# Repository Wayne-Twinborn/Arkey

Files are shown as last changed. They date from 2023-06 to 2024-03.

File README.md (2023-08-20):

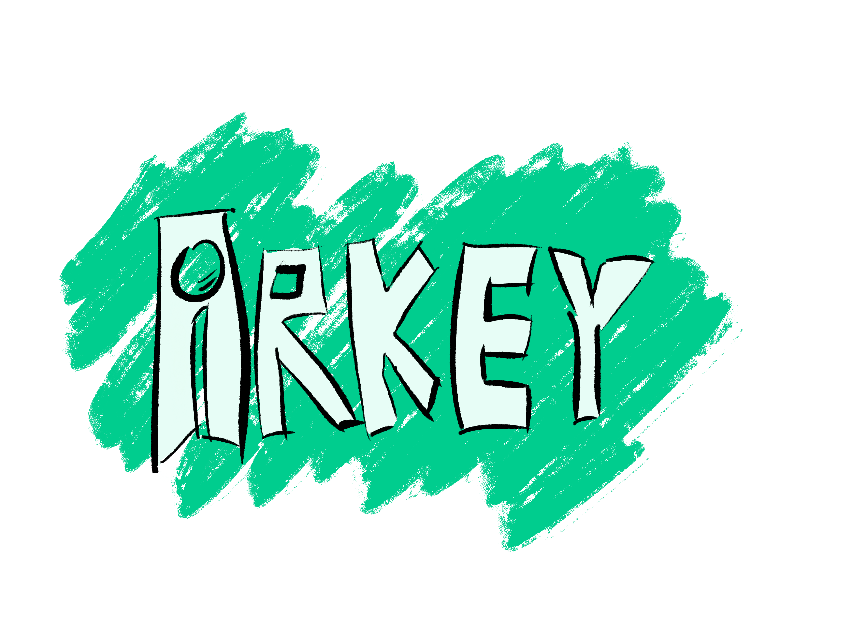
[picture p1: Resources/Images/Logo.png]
Arkey

Arcade Keyboard. Intended to be a super small form factor WASD controller for fighting games that's cheap and easy to source.  

## TLDR/I wanna get one  
If you want to build it yourself, check the "MakeMe" folder. You'll have to build it. I don't sell them at the moment. I'll probably gift off the batch of PCB I made. This project is to allow individuals and companies to have a cheap and easy option to build a stick. 

## About the project
This is a pet project because the only company (at the time I started) that was making super small form factor leverless controllers had all but abandoned their WASD line.   
Traditional leverless style (with up at the bottom of the controller) hurts my wrists and is unintuitive to me. This fixes both issues.   
My goal of giving myself a controller that suits my needs has been met. I'll continue to iterate on the design, but I want to turn it over to the community.   

# Versions
### ArkeyV1
This is the easiest one to build and source parts for. It uses standard 5 pin MX keyswitches and a pico with headers, hard soldered to the PCB. It's the largest entry in the project.

### ArkeyV2
This is a significantly improved Arkey. Much smaller size, uses hot swap sockets and switches, and the case can be printed on printers with a bed of around 190mmx 115mm. This is harder to assemble than the V1 by virtue of surface mounting the Pico and using hot swap sockets instead of mounting the switches directly. This is the recommended version of the Arkey.

### Arkey Nano V1
This is a version of the Arkey that uses keycaps instead of button caps. It's designed, effectively, to be an ergonomic keyboard to play on. This is the smallest option and it's easier to source keycaps than it is to source button caps.

### Licensing
This project is under the open source hardware license. Details are in the LICENSE file.
A short version is that you can distribute, produce, or modify as you like. No warranty or liabilty. 
I would be happy to see people building and selling the Arkey. 

## Contributing
If you want to contribute, the "Source" folder has all you need to work on the design. All of the tools I used to make it are freely available. And if you don't like them, there are plenty of alternatives. Chances are if you're going to dive into it  you already have tool preferences. 

#### Dev tools
- EasyEDA: PCB design for the V1 Arkey
- Kicad: PCB design for all other models. 
- FreeCAD: Case design  
- Krita: Art template  

### Contribution Requirements
You must include a description of what you've done and you must have a working prototype (meaning fully assembled PCB) on hand. 

I did this for free and will continue working on it when time and money allows, but if you do want to tip, here's my Ko-fi.
https://ko-fi.com/aloehart

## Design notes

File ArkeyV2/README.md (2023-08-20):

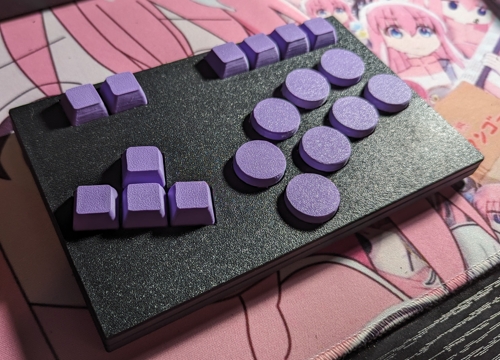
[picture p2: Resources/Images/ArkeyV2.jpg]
Arkey Nano

# Arkey V2  
This is the Arkey V2, a WASD based micro stick .  

## V2 Features  
- Hot swap socket design  
- Surface mount Pico (tested with waveshare usb-c pico as well)  
- Multiple 3D print case options  
- Significantly smaller form factor over V1    

Note: You can use whatever switches and cap designs you want that fit the sockets. This was designed for (and tested with) Choc v2.  
  
Pins (Using Xbox notation)  

Up:	11  
Down:	12  
Left:	10  
Right:	13  
A:	14  
B:	16  
X:	15  
Y:	17  
RT:	18  
RB:	19  
LT:	21  
LB:	20  
Start:	0  
Back:	1  
L3:	27   
R3: 	26  
Guide:	28  
Record: 22

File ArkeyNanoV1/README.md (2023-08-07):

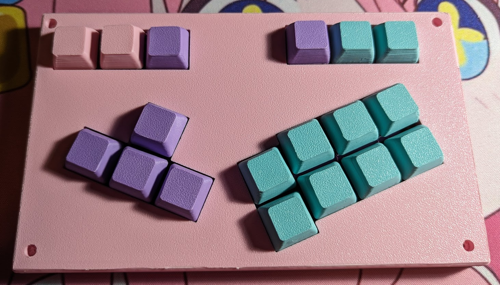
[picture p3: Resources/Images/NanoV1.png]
Arkey Nano


# Arkey Nano 
The Nano is a side project for Arkey. A form factor that's even smaller by basically making an ergonomic keyboard layout.

### Features:
- Incredibly small size
- Hot swap key switch mounts
- All the other features of the Arkey

### Requirements:
- PCB
- 18 Kailh hot swap sockets
- 18 Choc switches of your preference
- Key caps to fit the siwtches
- Raspberry Pi Pico (will be soldered surface mount)

### Reference the files in "MakeMe" for how to build it. 
### If you want to contribute, check the Readme in the source folder.

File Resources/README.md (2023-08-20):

This folder contains resources such as images and accessory STL files.

## MX Keycaps 
This is a flat topped MX key cap for 3d printing. An FDM printer should be able to print it with the top of the cap flat on the build plate without any supports. 

## Display Hooks
This is a simple hook design I threw together to hang my controllers with. Uploaded here by request.

## flash_nuke.uf2
A file that wipes your RP2040. When in doubt, use this to reset to a clean start.

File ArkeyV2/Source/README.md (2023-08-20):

# Tools used
- Kicad
- Freecad

# Firmware
Firmware is handled by the GP-2040-CE project. Arkey specifically just alters the Pico config to create its UF2.

# Rules
Anything you submit you must have a working prototype of first

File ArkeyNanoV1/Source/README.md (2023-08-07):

If you want to contribute, make sure you have a working prototype with your changes.

Documentation updates you can just push.

## Tools
- Kicad
- Freecad

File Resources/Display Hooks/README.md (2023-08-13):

These are simple hooks you can hang on your wall to display Arkey controllers. 

Screw.stl uses a screw and is countersunk into the hook. This has the highest weight limit (though I don't know how much and I wouldn't put any more than a controller on these).

Nail.stl is the same hook but designed to use a "picture hanging nail" to hang.a

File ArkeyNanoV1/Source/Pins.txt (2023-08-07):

1/start: pin 0 
2/select: pin 1
3/home/A1: pin 2
4/ls: 28
5/rs: 27
6/cap/A2: 26
D: 14
S: 13
A: 11
W: 12
K1/B1: 15
K2/B2: 18
K3/R2: 20
K4/L2: 22
P1/B3: 16
P2/B4: 17 (S2/config)
P3/R1: 19
P4/L1: 21

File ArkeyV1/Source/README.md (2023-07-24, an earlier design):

For this revision of the Arkey, the PCB is built using EasyEDA. That makes it easier to order on JLC. Future revisions I want to move to Kicad. 

The art template isn't perfect to the size of the buttons so be aware there will be areas outside the outlines that will be hidden.

The Acrylic is cut perfect to size so be aware your keycaps might be a tight fit in the function key row. Worst case scenario you can run it without the first and last caps. You can line it up though and have it work well. WASD and the button caps are fine though. 

## Contribution requirements
If you want to contribute to the hardware/art/case/etc, make sure you have a working prototype with your changes.

If you want to contribute to documentation, go ahead and put in a pull request.

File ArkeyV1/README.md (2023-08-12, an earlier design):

This is the first version of the Arkey

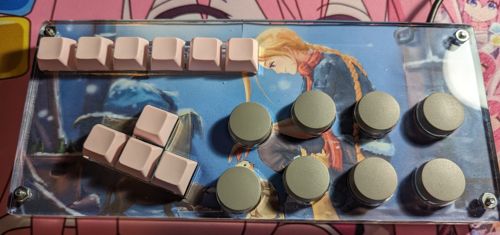
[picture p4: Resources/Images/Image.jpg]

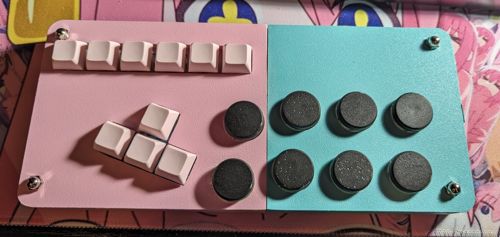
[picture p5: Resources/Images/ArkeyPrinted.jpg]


This version is perfectly usable and has been my primary controller for my 175ish hours of Street Fighter 6 so far. I love it very much. But it was also my first time putting together a pcb, first time working in freecad, and first time working with an FDM printer or acrylic.

Part of me wanted to just take this down and replace it with a new V1 because of its issues, but it works great and I love using it myself, so I'll leave it here.

The next revision is smaller and has drastic improvements from what I learned while creating the Nano v1. If you just have to have one, this one will do fine. But if you can wait for revision 2 (expected Sep 2023 at the latest) I would. It will have all the features but a lot of improvements.

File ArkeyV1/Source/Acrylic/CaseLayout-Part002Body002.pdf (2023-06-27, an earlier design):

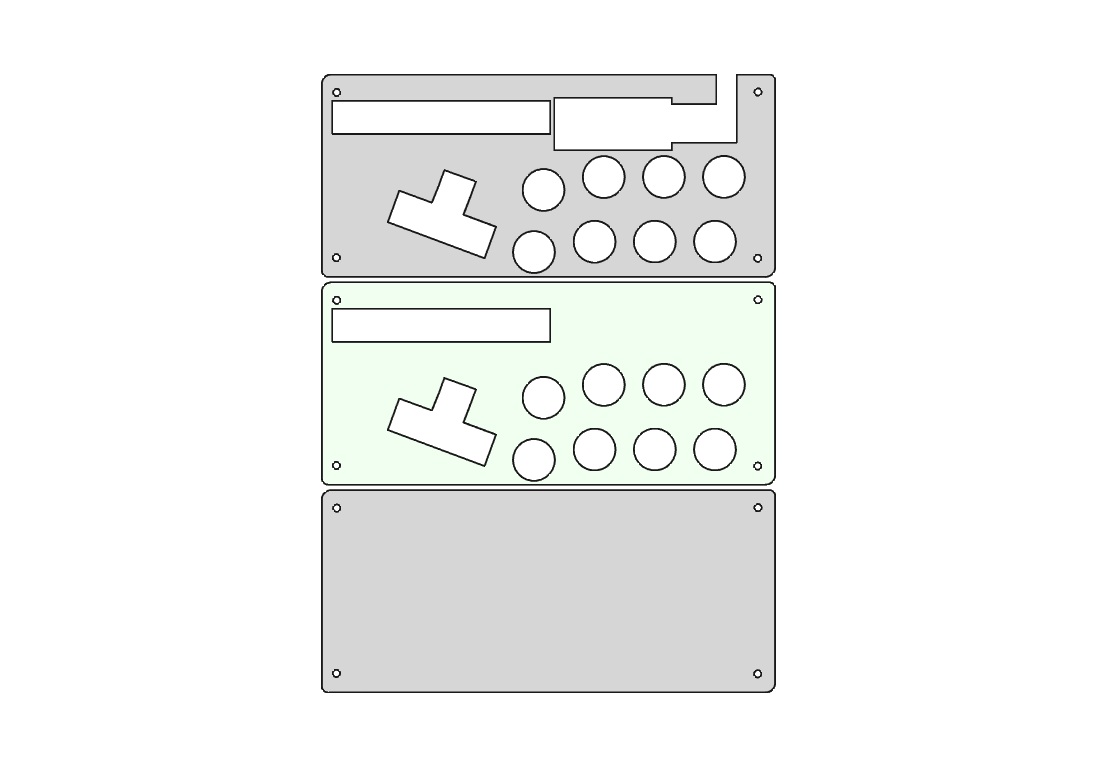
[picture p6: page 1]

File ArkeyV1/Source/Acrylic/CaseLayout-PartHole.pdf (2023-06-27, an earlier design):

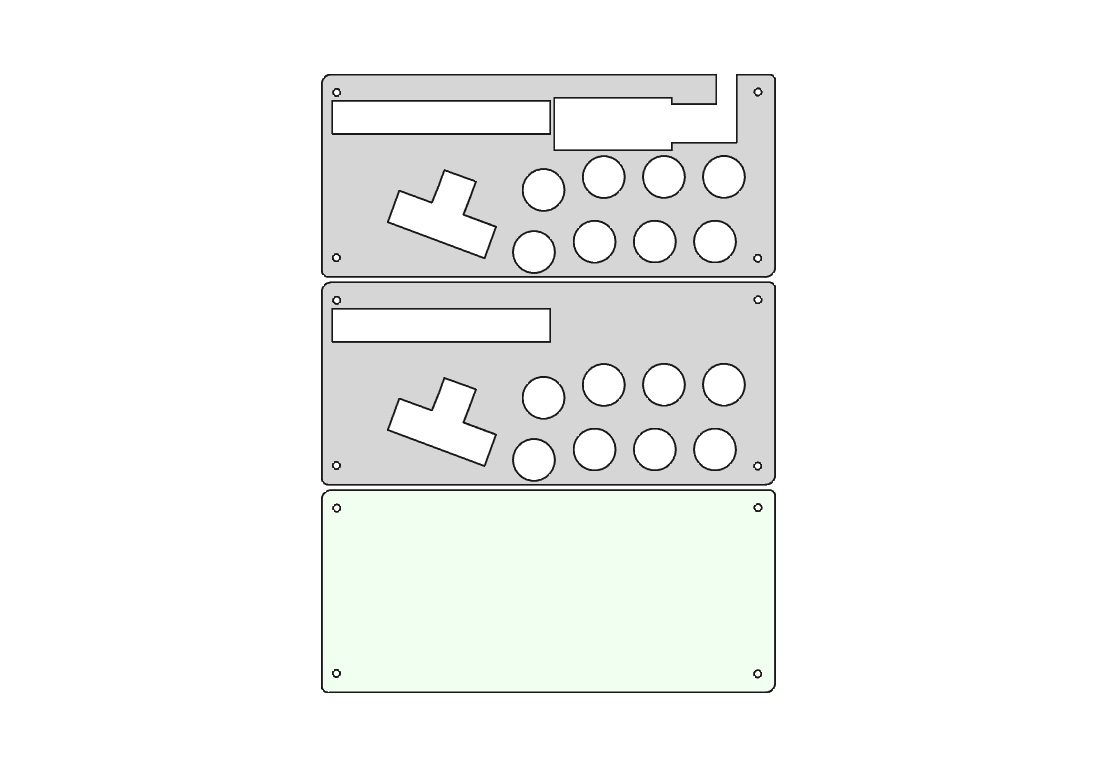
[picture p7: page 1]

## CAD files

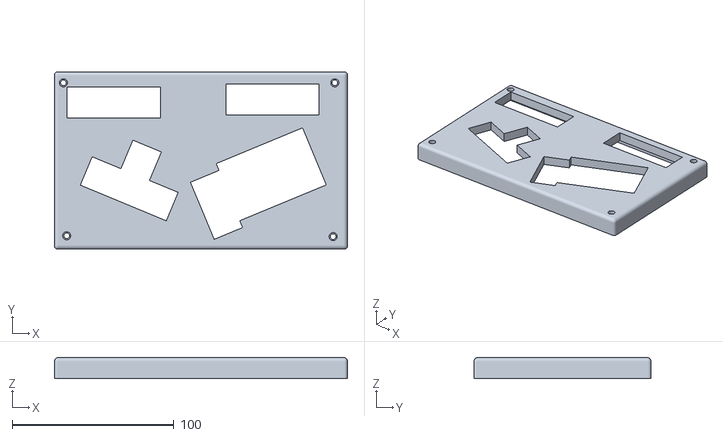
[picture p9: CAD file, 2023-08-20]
ArkeyNanoV1/MakeMe/Case/TopPlate.stl
181.0 x 109.5 x 13.0

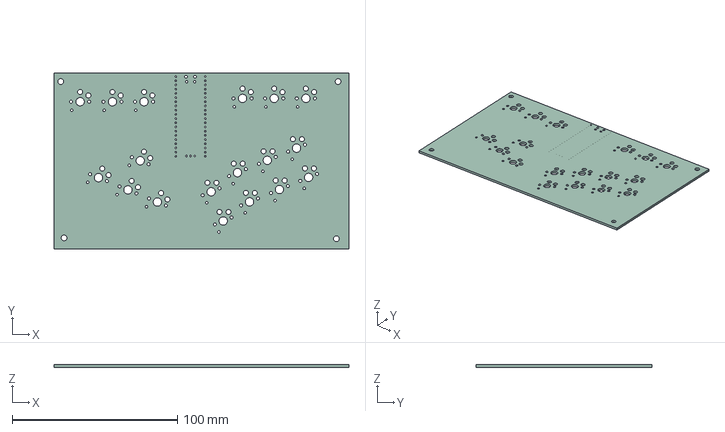
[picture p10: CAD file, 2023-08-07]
ArkeyNanoV1/Source/KiCad/NanoSwap.step
178.3 x 106.2 x 1.58 mm

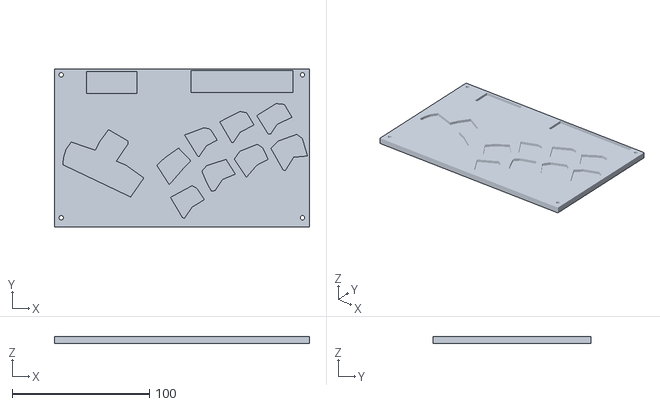
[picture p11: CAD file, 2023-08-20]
ArkeyV2/MakeMe/Case/3D Print/BottomPlate.stl
185.8 x 115.1 x 5.00

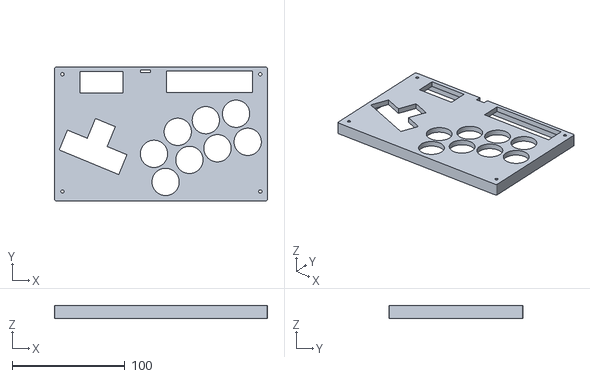
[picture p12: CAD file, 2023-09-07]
ArkeyV2/MakeMe/Case/Acrylic/TopPanel.stl
189.2 x 119.0 x 11.5

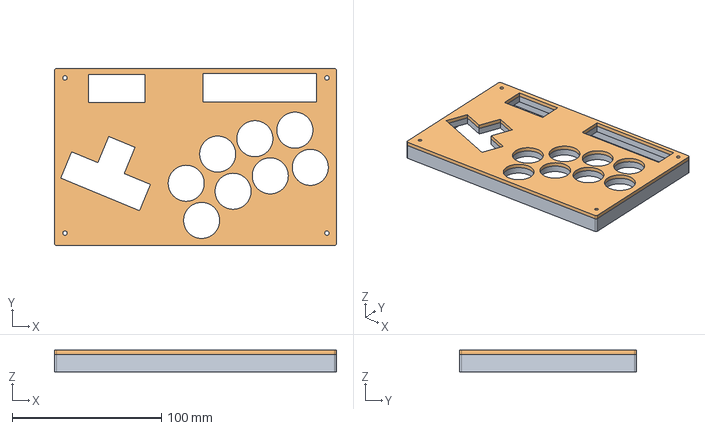
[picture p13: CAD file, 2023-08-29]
ArkeyV2/Source/Case/BaseCase.FCStd
189.2 x 119.0 x 14.5 mm
TopPlate-AcrylicBase
TopPlate-AcrylicPanel

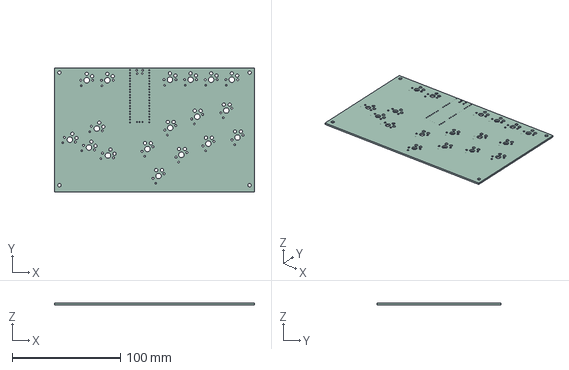
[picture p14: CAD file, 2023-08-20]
ArkeyV2/Source/PCB/ArkeyV2.step
184.9 x 114.3 x 1.58 mm

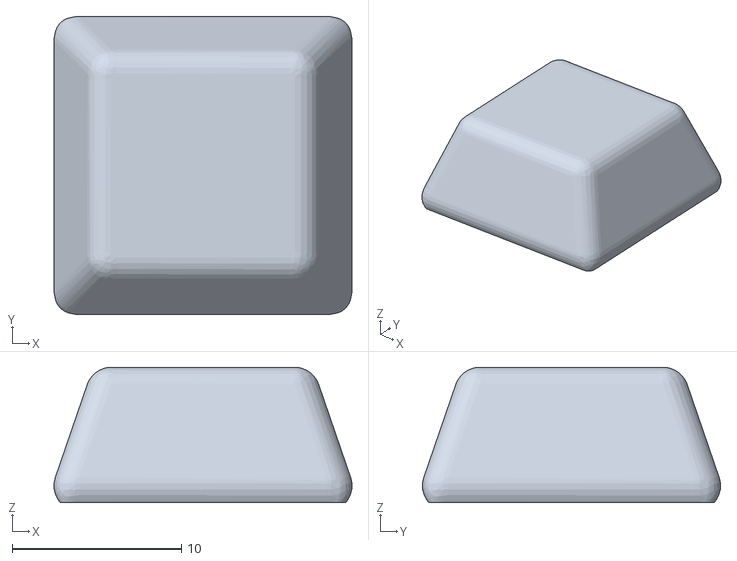
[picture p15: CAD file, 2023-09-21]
Resources/ArkeyCaps/LowProfileKeycap-v2.stl
17.6 x 17.6 x 8.00

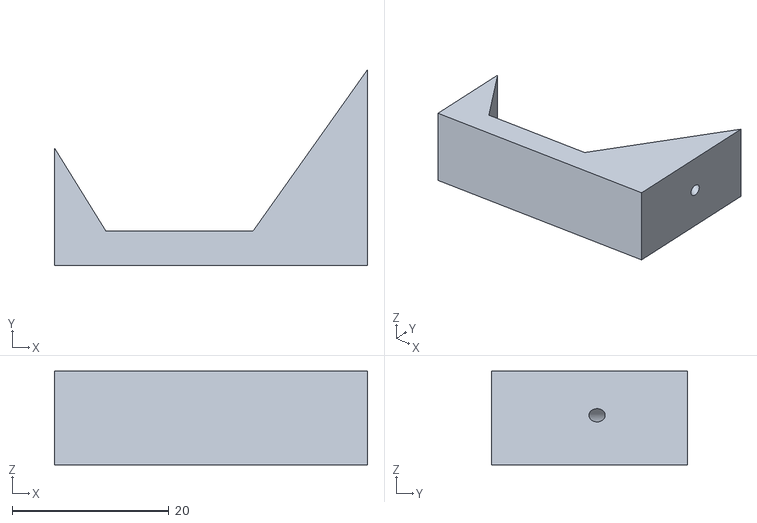
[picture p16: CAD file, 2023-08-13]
Resources/Display Hooks/Nail.stl
40.0 x 25.0 x 12.0

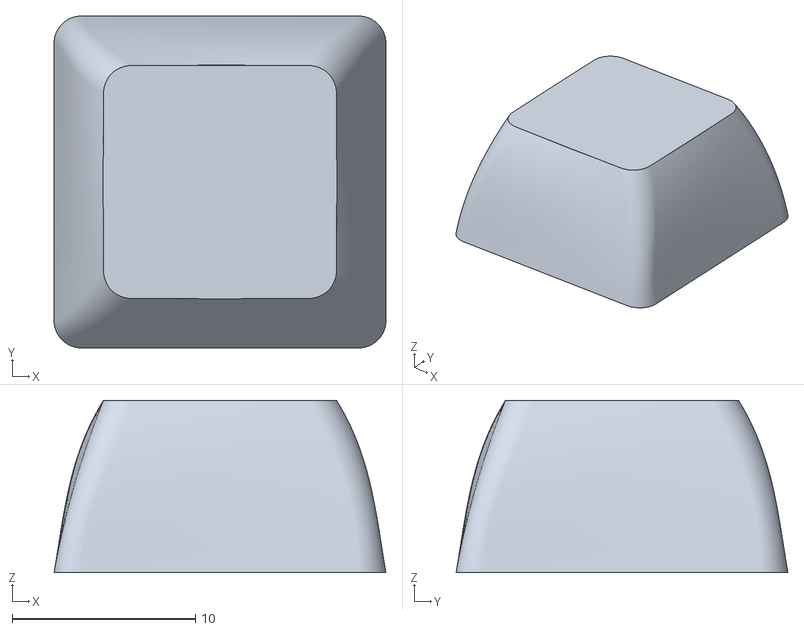
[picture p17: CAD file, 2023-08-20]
Resources/MX Keycaps/MXCap-Embed.stl
18.1 x 18.1 x 9.40

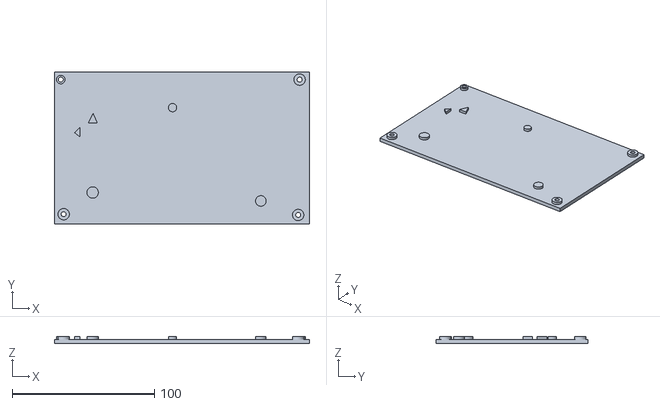
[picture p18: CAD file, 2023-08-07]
ArkeyNanoV1/MakeMe/Case/BottomPlate.stl
179.0 x 106.8 x 5.00

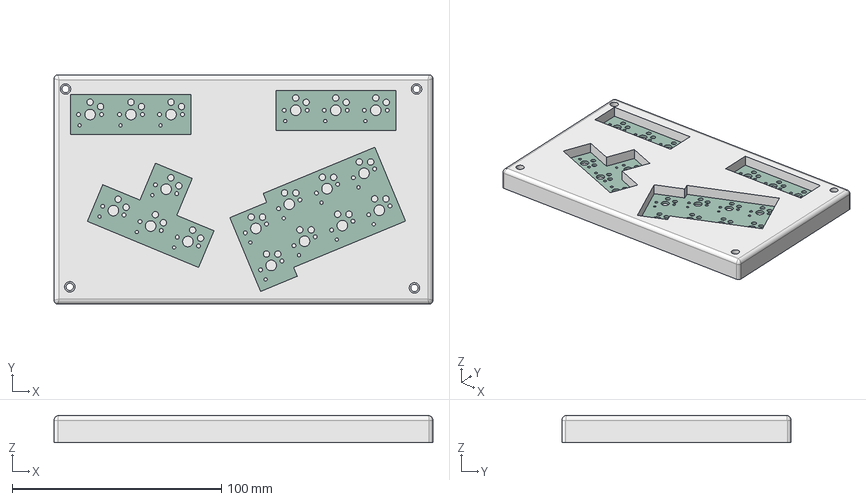
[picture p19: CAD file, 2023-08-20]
ArkeyNanoV1/Source/Case/3DPrintNanoV2.FCStd
181.0 x 109.5 x 13.0 mm
NanoSwap 1

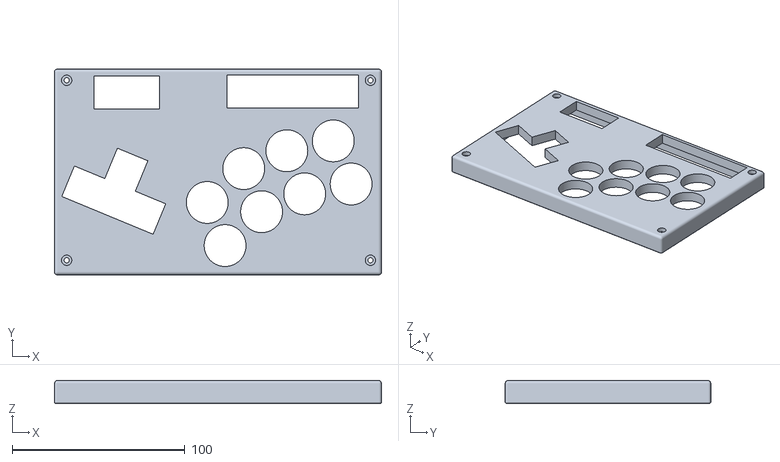
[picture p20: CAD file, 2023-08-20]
ArkeyV2/MakeMe/Case/3D Print/TopPanel-ThroughHole.stl
189.2 x 119.0 x 13.5

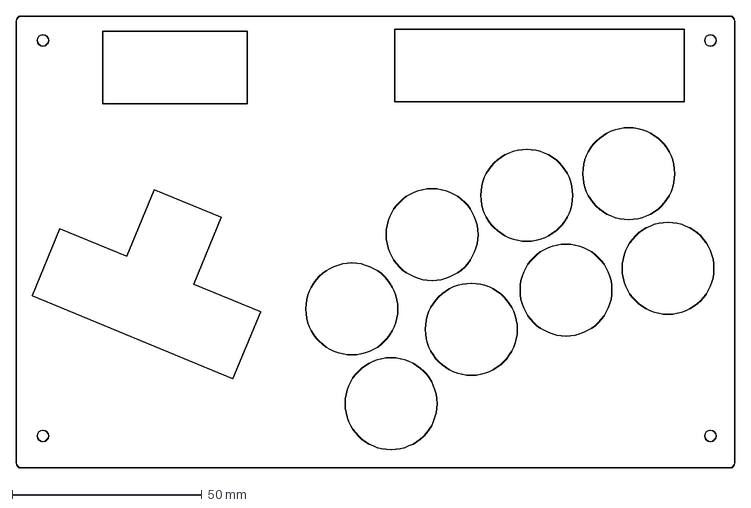
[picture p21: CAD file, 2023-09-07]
ArkeyV2/MakeMe/Case/Acrylic/AcrylicPanel.dxf
189.2 x 119.0 mm

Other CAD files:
Resources/ArkeyCaps/v1.FCStd
ArkeyV2/MakeMe/Case/3D Print/TopPanel-Heatset.stl
Resources/ArkeyCaps/LowProfileKeycap.stl
ArkeyNanoV1/Source/Case/3DPrintNano.FCStd
ArkeyV1/MakeMe/3D Print Case/Split Panels/BottomLeft.stl
ArkeyV1/MakeMe/3D Print Case/Split Panels/BottomRight.stl
ArkeyV1/MakeMe/3D Print Case/Split Panels/TopLeft.stl
ArkeyV1/MakeMe/3D Print Case/Split Panels/TopRight.stl
ArkeyV1/MakeMe/3D Print Case/Whole Panels/BottomPlate.stl
ArkeyV1/MakeMe/3D Print Case/Whole Panels/TopPlate.stl
ArkeyV1/MakeMe/Acrylic Case/CaseLayout-BottomPanel.dxf
ArkeyV1/MakeMe/Acrylic Case/CaseLayout-MiddlePanel.dxf
ArkeyV1/MakeMe/Acrylic Case/CaseLayout-TopPanel.dxf
ArkeyV1/Source/3D Print/ArkeyCase.FCStd
ArkeyV1/Source/Acrylic/CaseLayout.FCStd
ArkeyV1/Source/Acrylic/CaseLayout.dxf
Resources/ArkeyCaps/ButtonCap.stl
Resources/ArkeyCaps/v1-Keycap.stl
Resources/Display Hooks/Screw.stl

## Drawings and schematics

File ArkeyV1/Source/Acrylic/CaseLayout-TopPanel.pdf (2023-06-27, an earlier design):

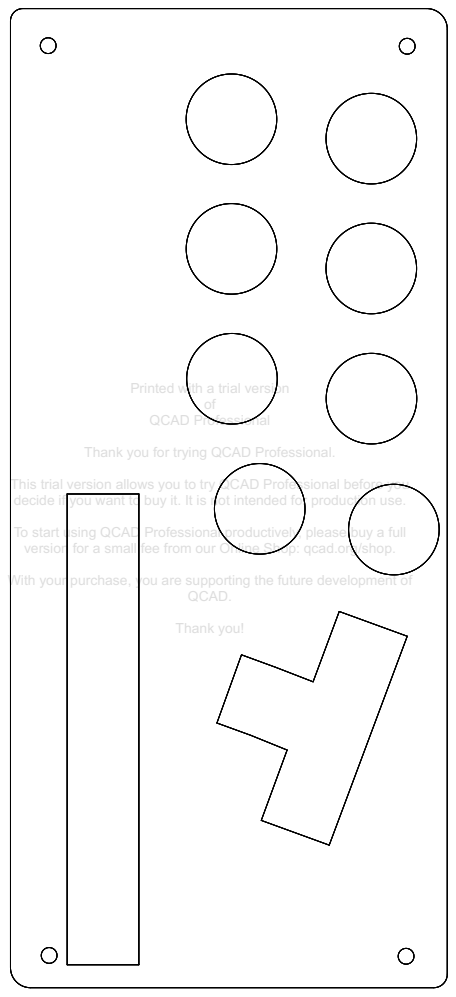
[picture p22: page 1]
of QCAD Professional; decide if you want to; buy it. It is not intended for production use. To start using QCAD; Professional productively, please buy a full; version for a small; fee from our Online Shop: qcad.org/shop. With your; purchase, you are supporting the future development of

Printed with a trial version

Thank you for trying QCAD Professional. This trial version allows you to try QCAD Professional before you

QCAD. Thank you!

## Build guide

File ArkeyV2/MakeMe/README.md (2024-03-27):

# What you need
- PCB
- Case
- 18 Kailh hot swap sockets
- 18 Choc v2 low profile switches
- 10 MX keycaps
- 8 MX buttoncaps
- Raspberry Pi Pico (or clone board with same pinout/form factor. NO HEADERS)
- USB cable
- M3 screws (10mm for through, 6mm for heatset)
- M3 nuts (through hole case)
- M3 heatset inserts (heatset case)

Do the following in order to keep from having to disassemble partway through

# PCB
- Order board (drop the GBR.zip file into the PCB manufacture of your choice. I use JLCPCB)
- Solder sockets onto the back of the board
- Solder pico to the front of the board 
**IMPORTANT NOTE** this is designed to be surface mounted to the board. Do not use a pico with headers!
- Insert your keyswitches
- Put on your key/button caps

# Firmware
- Hold the Bootsel button on your Pico until it is loaded. 
- Drop the "flash_nuke.uf2" file from the resources folder in the Arkey github onto your pico.
- Wait for it to fully reboot and open as a drive again.
- Drop the ArkeyV2.uf2 file onto the pico.
- Wait for the reboot.

# Case
- Print bottom plate
- Print either the through hole or heatset insert top plate (your choice)

# Assembly
- Place PCB onto bottom plate, it only goes on one way.

### Through hole assembly
- Place the top plate over the PCB and bottom plate.
- Place your nuts in the sunken holes on the top plate
- Screw M3 screws through the mounting holes on the bottom plate up and into the nuts on top
- Screw snug but don't overtighten

### Heatset assembly
- Use your heating tool (I use a soldering iron and 20mm M3 screw) to gently press the inserts into the mounting holes
- Make sure they are alighned correctly using a longer screw. Check that the screw is straight up and down
- Place the top plate over the PCB and bottom plate
- Screw the M3 screws through the bottom plate. Do not over tighten. It should fit snug. 

# Acrylic Case
The acrylic case assembly is the same as the through hole with the exception of the acrylic panel itself. You'll want your fasteners to go through the bottom plate, top panel, and acrylic panel. This case is designed for 3mm thick laser cut acrylic. Use the DXF file in that folder.

### Art
The art template is a .kra file. This is the native format for Krita. Krita is a free and open source software that's used for painting. There's a layer for you to just drop and position your art.
For sizing, if you know how to do it you can do it yourself sizing for 189.2x119mm.

If you don't, then save your art at 300 pixels per inch/dpi/ppi and resize to 2234.6x1405.5 pixels. If it doesn't let you do decimals in your art that's fine. Then make sure whatever you're printing with prints at 300 dpi.

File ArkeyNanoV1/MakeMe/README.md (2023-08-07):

# Parts Needed
- PCB
- 18 Kailh hot swap sockets
- 18 of your preferred switches compatible with the Kailh sockets
- 18 keycaps to fit the switches
- Raspbery Pi Pico

# PCB
Just upload the .zip file in the PCB folder to your preferred PCB manufacturer's site.

### Assembly
- Solder the sockets to the back of the PCB (the side without the logo)
- Solder the Pico to it's pads on the front of the PCB. This will be surface mount, do not use headers or a pico with headers unless you're going to custom design your own case.
- Insert your keyswitches into the sockets
- Put your keycaps on the switches

# Firmware
Hold the bootsel button on the pico while plugging it into your computer
Drop the .uf2 file from the Firmware folder onto the pico. It will reboot. Once it finishes rebooting, your controller should function. 

# Case
There are 2 STL files in the Case folder, print both. You'll need 3.5mm thickness screws of your preferred type to assemble the controller with case. 

### Assembly
There are 2 arrows on the bottom plate, they point up and left. Place them on the left side.
Place the PCB onto the bottom plate.
Place the top plate over the PCB and bottom plate. The bottom of the bottom plate "should" be flush with the bottom lip of the top plate.
Insert your fasteners through the holes on the bottom plate and attach however you prefer. I like to use flat head screws going through the bottom with cap nuts on the top, allowing me access to internals by hand. And I put rubber feet over the head of the screws.

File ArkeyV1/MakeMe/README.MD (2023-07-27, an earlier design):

# Parts you need:
- Raspbery Pi Pico with soldered headers
- Keyboard MX 5 style pin key switches: https://www.amazon.com/gp/product/B09314WK5Z
- 10 MX style keycaps to fit the switches
- 8 22mm button caps to fit the right half: https://www.amazon.com/dp/B0BKDBFBMP
- Micro USB cable
- The PCB (import the easyeda file into easyeda and order it through jlcpcb)
- The case (optional, local or use SendCutSend)
- Rubber feet (optional if not using case): https://www.amazon.com/gp/product/B07CNQC695	
- Size 6 machine bolts 1" long (optional, only for case)

# Assembly
## Board
- Solder key switches
- Solder Pico with USB facing to the right

## Case
### Acrylic
- Plate order is Bottom > PCB > Middle > Top
- Use the rubber feet on the bottom of the PCB to provide spacing from the bottom plate
- Size 6 machine bolts. Length depends on how you want to cap them. Take it to the hardware store. 
- For the art, you can print it on standard 8.5x11 paper without issue. Be aware that the template markings are smaller than  the actual cut out in order to prevent an outline being visible. 
  
### 3D Print
- Whole panels
- Print the 2 panels in the folder
- Push size 6 machine screws through the bottom plate going up, pushing them into the counterbore holes.
- Optionally cover the screw heads with rubber feet
- Place the PCB on the 4 bolts on top of the plate with the 3 support posts in a row on the right side.
- Feed your USB solution through the hole (If you're going to use a panel mount option, make sure you stick the cable to the top plate so it doesn't interfere with buttons)
- Place the top plate over the 4 bolts until they poke up.
- Apply the nut of your choice. I like cap nuts myself

- Split Panels
- If you can, print the bottom panel whole from the whole panels folder. It's worth it to use the extra time and filament to print at an angle with support and get that panel whole.
- If you have a whole bottom panel, print the top left and top right panels.
- Fit the 2 halves together. Depending on your filament, print settings, printer, etc you may need to do some sanding to make them fit snug. 
- If you don't have a whole bottom, print the bottom halves and fit them together.
- Follow the steps after printing in the whole panel section.

- For whole panels, use size 6 machine bolts through the bottom panel, push to force them into the counterbore holes. Slide the pcb onto the bolts on top (the 3 support pillars go on the right)

## Firmware
### Custom config method
- Hold the bootsel button on your Pico and plug it into your PC, it will be recognized as a USB drive.
- Drop Arkey.uf2 onto the Pico. 
- It will reboot on its own and you should have a working controller.
- Hold the leftmost button on the top row while plugging in to get into webconfig if you want to change settings. 

### Official direct method
- If you want to do it manually, you can obtain the firmware direct from the community and configure it manually.
- Get the firmware you need at https://gp2040-ce.info/ and follow their instructions to install it.
- Hold the rightmost button on the top row while plugging in the controller to access the web config.
- Under Configuration > Data Backup and Restoration, import the Backup.gp2040 backup file.
- Click the Reboot button and you should have a working controller.
- The leftmost button will now be S2 and be used to get into the web config. 

# Button Layout
From left to right on the top row
- Start
- Select 
- Home
- L3
- R3
- Screenshot

Buttons are standard layout for a modern stick. 
Top button row from left to right
- Square/X
- Triangle/Y
- R1/RB
- L1/LB

Bottom row
- X/A
- Circle/B
- R2/RT
- L2/LT

# Buttons
You can find compatible 3d printable caps at https://github.com/sgfdevices/Bridget/tree/main/Buttons

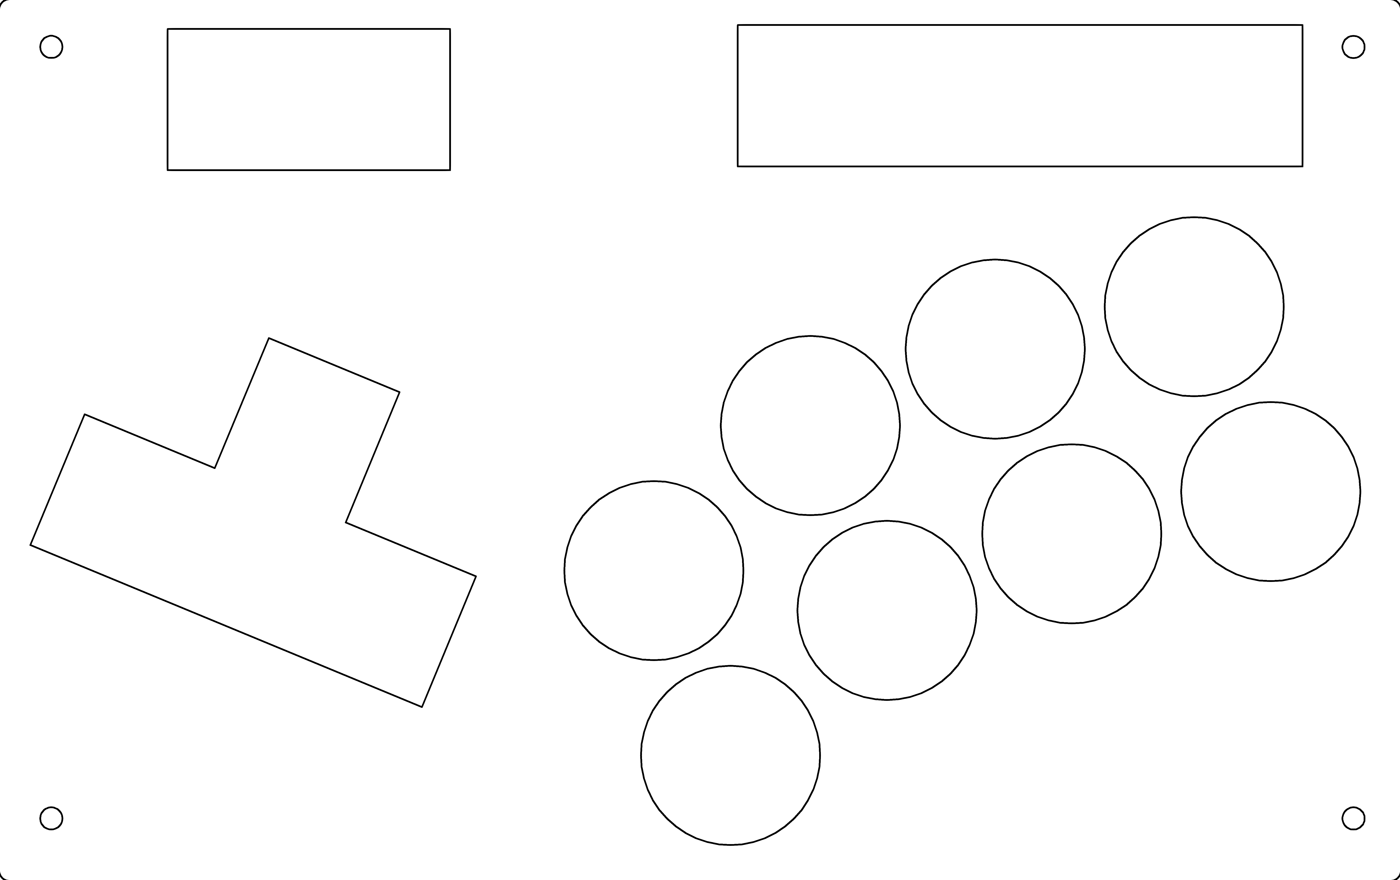
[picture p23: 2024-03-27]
ArkeyV2/MakeMe/Case/Acrylic/ArtTemplate.png

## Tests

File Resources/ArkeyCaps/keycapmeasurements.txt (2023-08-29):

bottom 18mm
top 13mm
height 9.6
8mm from base of stem
1.5mm wall

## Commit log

2023-06-27 Init
    No config file for GP2040-CE yet as I haven't gotten my first pcb yet to configure it myself. Release day comes right after that.
    [CaseLayout-BottomPanel.dxf, CaseLayout-MiddlePanel.dxf, CaseLayout-TopPanel.dxf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]
2023-06-29 Just fixing up a readme and testing my git setup on my framework.
2023-07-03 Working on re-creating in KiCad
    To hopefully get more control and more consistency.
    [NanoSwap.kicad_pcb, NanoSwap.kicad_sch]
2023-07-04 Time for traces
    [NanoSwap.kicad_pcb]
2023-07-07 Laying down some '''groundwork'''
    [NanoSwap.kicad_pcb]
2023-07-09 Maybe production ready?
    [NanoSwap.kicad_pcb]
2023-07-12 Public Release finally
    [NanoSwap-B_Cu.gbr, NanoSwap-B_Mask.gbr, NanoSwap-B_Paste.gbr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]
2023-07-24 Logo and restructure
    Cleaning up the folder structure to make things cleaner for future revisions and alternates (the Nano is coming soon)
    [CaseLayout-BottomPanel.dxf, CaseLayout-MiddlePanel.dxf, CaseLayout-TopPanel.dxf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]
2023-07-27 3D printable case and custom uf2
    [ArkeyCase.FCStd, BottomLeft.stl, BottomPlate.stl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]
2023-07-30 Added keycap file for the project.
    [mxkeycap-Embed001.stl]
2023-08-02 The keycaps get stuck on some switches. Removing until fixed
    [mxkeycap-Embed001.stl]
2023-08-07 Arkey Nano push
    [3DPrintNano.FCStd, 3DPrintNanoV2.FCStd, BottomPlate.stl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]
2023-08-13 Uploading display mount per request
    [Nail.stl, Screw.stl]
2023-08-20 Arkey V2 init
    [3DPrintNanoV2.FCStd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]
2023-08-20 Corrected Filename
    [BaseCase-TopPlate-Through.stl]
2023-09-07 Time for the Art case for the V2 Arkey! Check the readme for more info.
    [AcrylicPanel.dxf, BottomPlate.stl, TopPanel-Heatset.stl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]
2023-09-21 Improved button and key caps.
    [ButtonCap.stl, LowProfileKeycap-v2.stl, LowProfileKeycap.stl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]
2024-03-27 Update to V2 instructions
    We've had someone try to build an Arkey with a pico that has headers. Updated the documentation to make it clear that it's meant to be surface mounted.
